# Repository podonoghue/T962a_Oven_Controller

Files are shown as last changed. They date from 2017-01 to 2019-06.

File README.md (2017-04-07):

# T962a Oven Controller Upgrade

This is a replacement controller for a T962a Oven.  
It consists of a complete replacement for the existing controller in a mechnically compatible form.    
It provides open source firmware that provides extended features.  
It also provides a basic JAVA application to control the oven in a more convenient fashion (Work in Progress)

**Features**  
- Supports the two internal thermocouples  
- Support up to two external thermocouples (with expansion board)  
- Supports up to 10 profiles stored in non-volatile memory  
- The current configuration is also stored in non-volatile memory  
- Uses an additional SSR to completely separate the low-voltage and high-voltage components  

**Requirements**  
- It uses a Kinetis microcontroller so requires a compatible programmer e.g. USBDM  
- Firmware development requires Eclipse/KDS and USBDM plugin  

# Software and Firmware

This is a Eclipse workspace.   
 
Basic application - work in progress.  
Firmware for oven controller.  

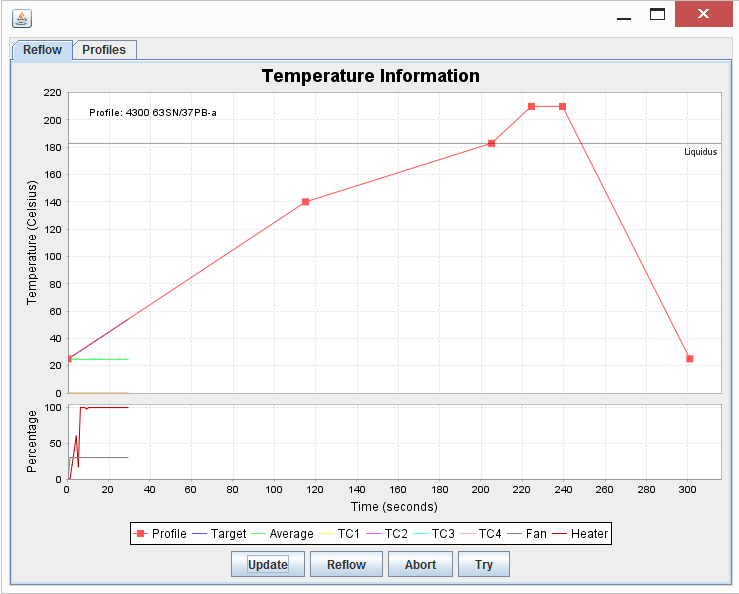
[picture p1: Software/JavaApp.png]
An image Java Application
  

[Available here](https://github.com/podonoghue/T962a_Oven_Controller/tree/master/Software)  

# Windows Drivers (none needed for Linux)

[Available here](https://github.com/podonoghue/T962a_Oven_Controller/tree/master/WinDrivers)  

# Hardware (PCB Designs)

PCB designs for replacement oven controller.  
These are Altium designer projects.  
Gerber files are also provided.  
Bare boards may be ordered from OSH Park

[Hardware designs are available here](https://github.com/podonoghue/T962a_Oven_Controller/tree/master/Hardware)

Main board
====

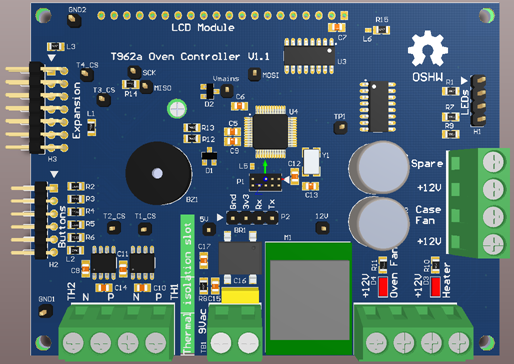
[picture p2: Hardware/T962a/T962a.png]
  

Expansion board
====

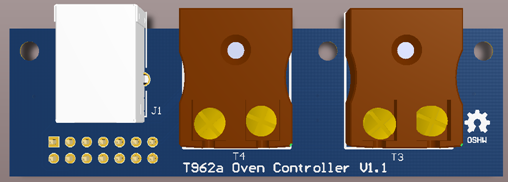
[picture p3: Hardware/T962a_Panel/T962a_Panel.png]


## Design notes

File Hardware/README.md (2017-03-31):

# T962a Hardware (PCB Designs)
  
PCB designs for T962a replacement oven controller.  
These are Altium designer projects.  

Main board
====
Refer to the PDFs in the Project Outputs directory of each project  <a href="T962a/Project%20Outputs%20for%20T962a/T962a.PDF">Main Board</img></a>  

An image Top Board Image  

PCBs may be ordered from OSH park    
Expansion board
====
Refer to the PDFs in the Project Outputs directory of each project  <a href="T962a_Panel/Project%20Outputs%20for%20T962a_Panel/T962a_Panel.PDF">Expansion Board</img></a>  

An image Top Board Image  

PCBs may be ordered from OSH park

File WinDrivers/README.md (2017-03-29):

# T962a Serial Driver  

Files to build Windows CDC driver for T962a controller  
This allows the controller to be accessed as a USB serial port

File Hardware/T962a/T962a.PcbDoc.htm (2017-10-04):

Reporting Options

# File in Previous Format

Date | : | 10/09/2017
Time | : | 8:55:08 PM
Filename | : | C:\Users\podonoghue\Documents\Development\T962a_Oven_Controller\Hardware\T962a\T962a.PcbDoc

Version | Warning

This file was generated by an earlier version of the software

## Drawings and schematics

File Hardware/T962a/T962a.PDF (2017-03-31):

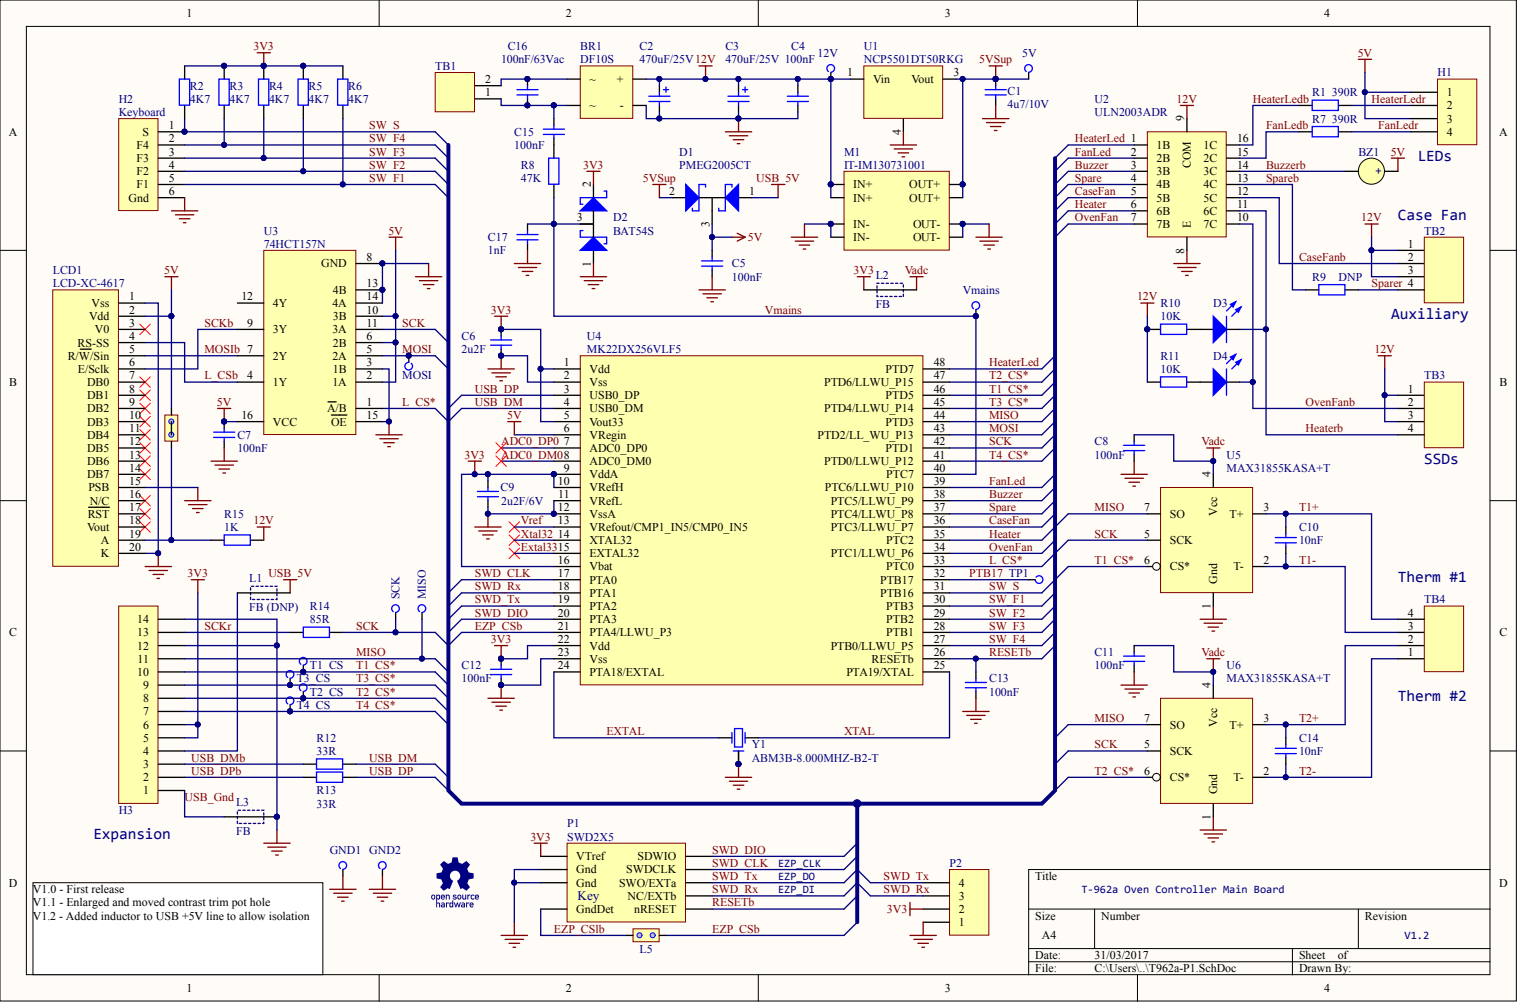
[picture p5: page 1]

SW_F3
SW_F2

CaseFanb

T3_CS T3_CS*
T2_CS T2_CS* | EXTAL | XTAL

USB_DPb | USB_DP

V1.0 - First release
V1.1 - Enlarged and moved contrast trim pot hole
V1.2 - Added inductor to USB +5V line to allow isolation

T-962a Oven Controller Main Board

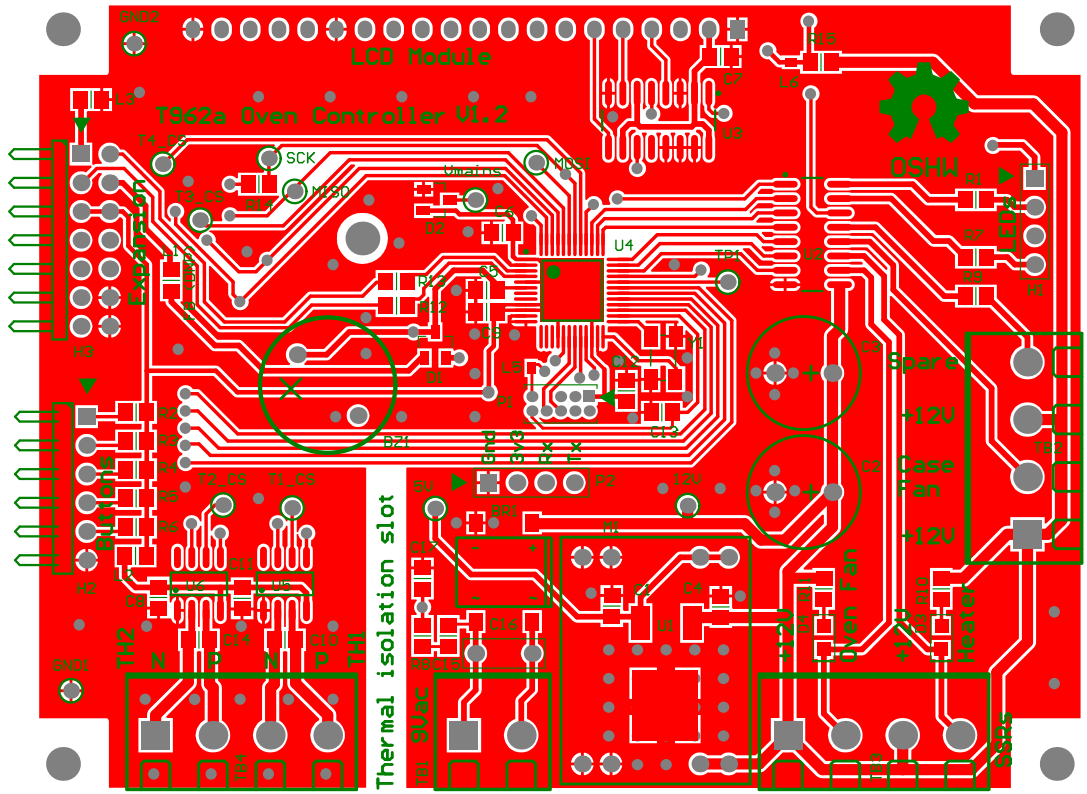
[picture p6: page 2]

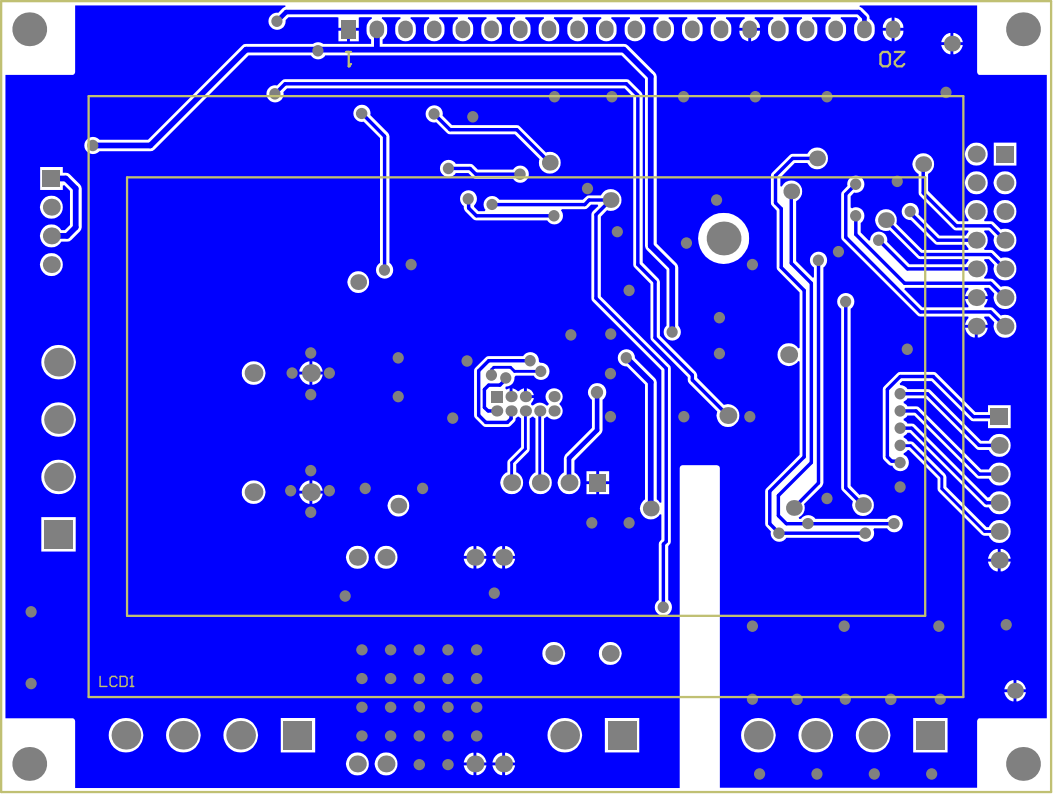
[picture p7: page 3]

Bill of Materials | Bill of Materials For Project [T962a.PrjPCB] (No PCB Document Selected)
Source Data From: | T962a.PrjPCB
Project: | T962a.PrjPCB
Variant: | None
Creation Date: | 31/03/2017 | 11:26:18 AM
Print Date: | 31-Mar-17 | 11:26:27 AM
Footprint | Comment | Farnell PN | Digikey | Designator | Description | Quantity
PCBPIN - 0.9mm | TP | | | 5V, 12V, GND1, GND2, MISO, MOSI, SCK, T1_CS, T2_CS, T3_CS, T4_CS, TP1, Vmains | Test Point | 13
Bridge-SMT | DF10S | 2101164 | | BR1 | bRIDGE rECTIFIER | 1
BUZZER_Small | Buzzer_PCB | | | BZ1 | Buzzer (Adafruit 1536) | 1
CCNP2012-0805 | 4u7/10V | | | C1 | Capacitor SMT 0805 | 1
RB5/10x13mm | 470uF/25V | 2469425 | | C2, C3 | Polarized Capacitor | 2
CCNP2012-0805 | 100nF | | | C4, C5, C7, C8, C11, C12, C13, C15 | Capacitor, Capacitor, Capacitor, Capacitor SMT 0805, Capacitor SMT 0805, Capacitor, Capacitor SMT 0805, Capacitor | 8
CCNP2012-0805 | 2u2F | | | C6 | Capacitor | 1
CCNP2012-0805 | 2u2F/6V | | | C9 | Capacitor | 1
CCNP2012-0805 | 10nF | | | C10, C14 | Capacitor SMT 0805 | 2
CAP - small MKT | 100nF/63Vac | 2429336 | | C16 | Capacitor | 1
CCNP2012-0805 | 1nF | | | C17 | Capacitor | 1
SOT23 | PMEG2005CT | 2459194 | | D1 | Dual Schottky Diode (SMT) | 1
SOT23 | BAT54S | F1467519 | | D2 | Dual Diode (SMT) | 1
LED-SMT-2 | LED Red | 5790839 | | D3, D4 | LED (Red SMT) | 2
HDR1X4S | Header 1x4 | | | H1, P2 | Header, 5-Pin, Right Angle | 2
HDR1X6H | Keyboard | | | H2 | Header, 6-Pin | 1
HDR2X7H | 2x5 Header | | | H3 | Header 2x7 | 1
CR2012-0805 | FB | 1515661 | | L2, L3 | Ferrite Bead (0805) 0.045OHM, 2A | 2
LCD_XC-4617 | LCD-XC-4617 | | | LCD1 | LCD 128 x 64 pixel, ST7920 controller & contrast pot (Jaycar XC-4617) | 1
IT-IM130731001 | IT-IM130731001 | | | M1 | Itead Buck converter | 1
SWD-2x5 | SWD2X5 | | | P1 | SWD Connector 2x5-Pin | 1
CR2012-0805 | 390R | | | R1, R7 | Resistor | 2 5 1 1 2 2 1 1 1 3 1 1 1 1 2 1
CR2012-0805 | 4K7 | | | R2, R3, R4, R5, R6 | Resistor
CR2012-0805 | 47K | | | R8 | Resistor
CR2012-0805 | DNP | | | R9 | Resistor
CR2012-0805 | 10K | | | R10, R11 | Resistor
CR2012-0805 | 33R | | | R12, R13 | Resistor
CR2012-0805 | 85R | | | R14 | Resistor
CR2012-0805 | 1K | | | R15 | Resistor
MOLEX-39544-3002 | Terminal2 | 2396251 | | TB1 | MULTICOMP MC24366 Wire-To-Board Terminal Block
MOLEX-39544-3004 | Terminal4 | 1624302 | | TB2, TB3, TB4 | MULTICOMP MC24368 Wire-To-Board Terminal Block
TO-252 | NCP5501DT50RKG | 2532866 | | U1 | Fixed LDO Voltage Regulator, 2.5V-16V in, 230mV Dropout, 5V/500mA out, TO-252-3
SO-16_N | ULN2003ADR | 1470513 | | U2
SO-16_N | 74HCT157N | | | U3 | Quad 2-1 Multiplexor
TSQFP50P900X900-48M | MK22DX256VLF5 | | | U4 | Arm Cortex M4
SO-8_L | MAX31855KASA+T | 2515622 | | U5, U6
Crystal_SMT - ABM3B | ABM3B-8.000MHZ-B2-T | 2467818 | | Y1 | Crystal 8MHz (MINIATURE SMT ABM3B)
| | | | | | 71
Approved | | Notes

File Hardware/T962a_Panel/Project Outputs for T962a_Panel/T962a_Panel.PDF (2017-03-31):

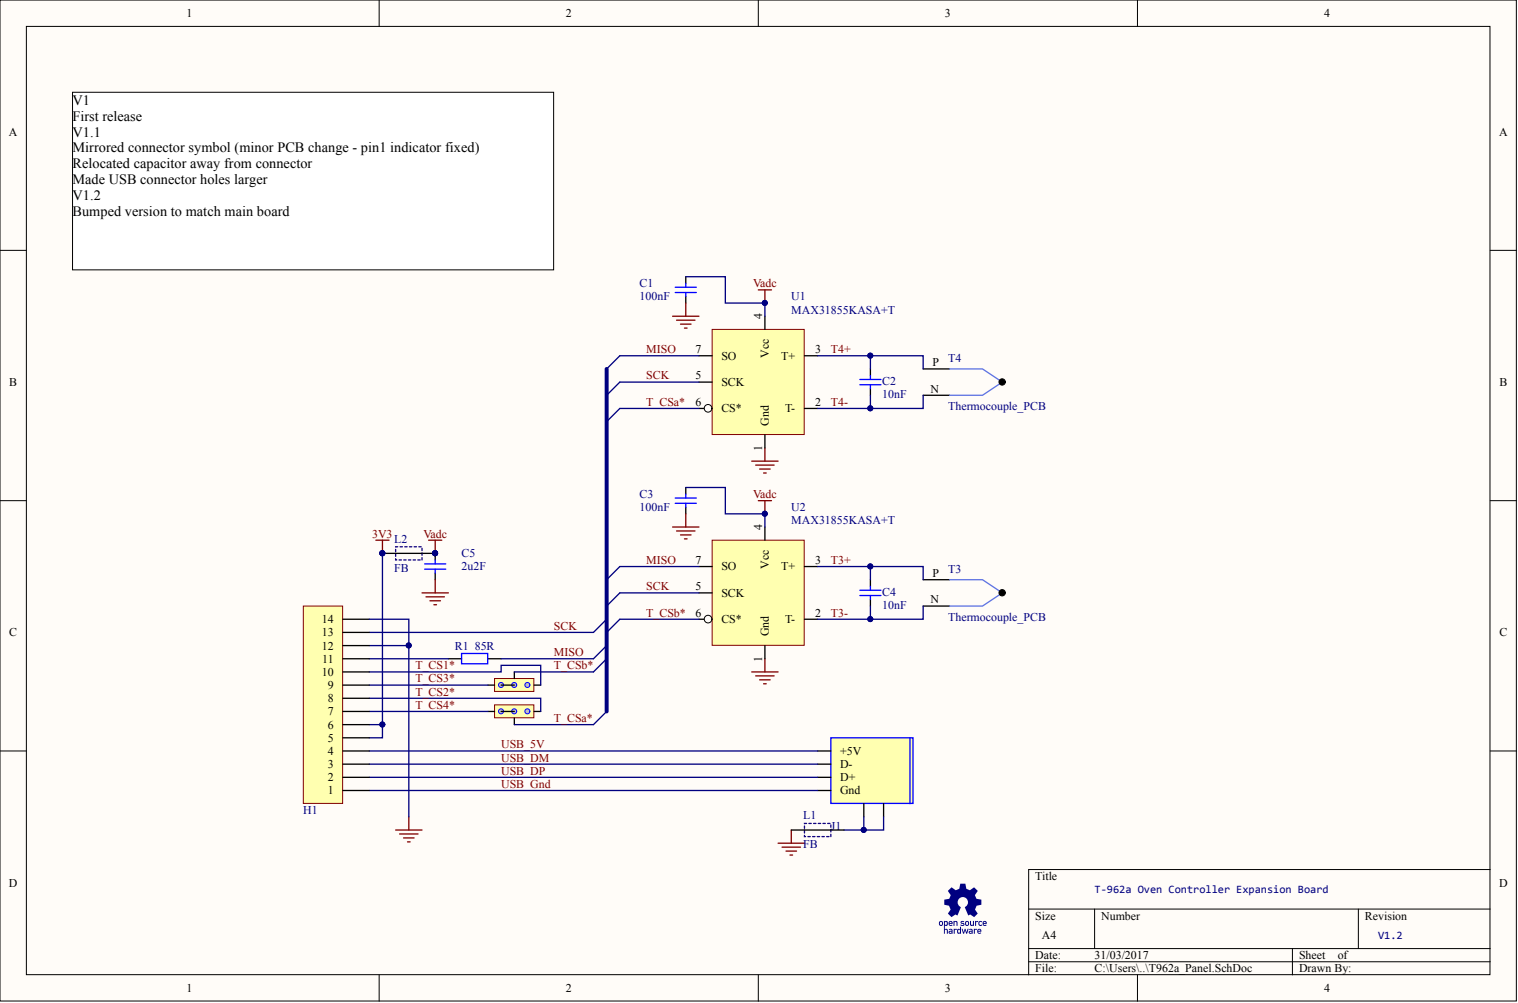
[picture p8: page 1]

First release
Mirrored connector symbol (minor PCB change - pin1 indicator fixed)
Relocated capacitor away from connector
Made USB connector holes larger
Bumped version to match main board

USB_DM
USB_DP
USB_Gnd

T-962a Oven Controller Expansion Board

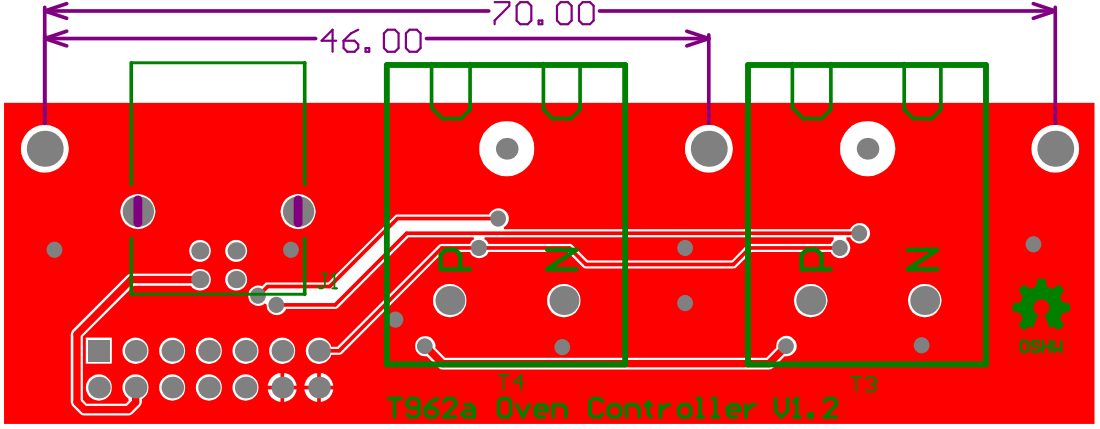
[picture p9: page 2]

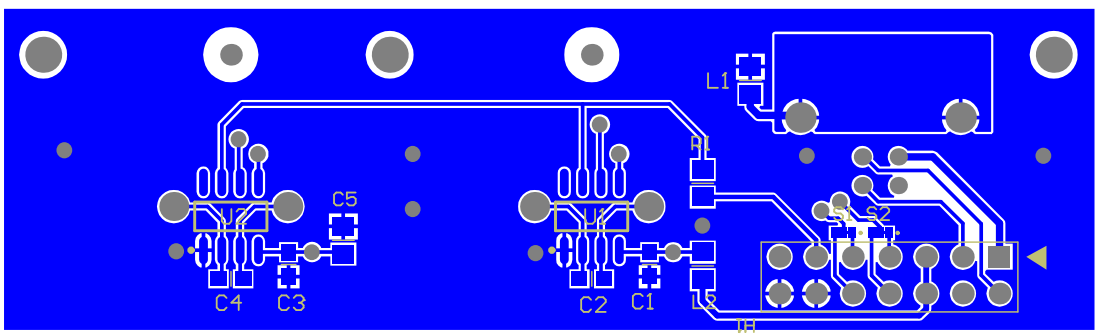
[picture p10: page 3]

Bill of Materials | Bill of Materials For Project [T962a_Panel.PrjPCB] (No PCB Document Selected)
Source Data From: | T962a_Panel.PrjPCB
Project: | T962a_Panel.PrjPCB
Variant: | None
Creation Date: | 31/03/2017 | 11:37:54 AM
Print Date: | 31-Mar-17 | 11:37:59 AM
Footprint | Comment | Farnell PN | Digikey | Designator | Description | Quantity
CCNP1608-0603 | 100nF | | | C1, C3 | Capacitor | 2
CCNP1608-0603 | 10nF | | | C2, C4 | Capacitor | 2
CCNP2012-0805 | 2u2F | | | C5 | Capacitor | 1
HDR2X7S | 2x5 Header | | | H1 | Header 2x7 | 1
USB_BCon - straight pins | USB Type B | | | J1 | USB B Connector | 1
CR2012-0805 | FB | 1515661 | | L1, L2 | Ferrite Bead (0805) 0.045OHM, 2A | 2
CR2012-0805 | 85R | | | R1 | Resistor | 1
ThermoCoupleSocket - PCB mount | Thermocouple_PCB | 2347189 | | T3, T4 | | 2
SO-8_L | MAX31855KASA+T | 2515622 | | U1, U2 | | 2
| | | | | | 14
Approved | | Notes

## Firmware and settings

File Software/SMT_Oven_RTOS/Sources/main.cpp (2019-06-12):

/*
 ============================================================================
 * @file    main.cpp (180.ARM_Peripherals)
 * @brief   Basic C++ demo using GPIO class
 *
 *  Created on: 10/1/2016
 *      Author: podonoghue
 ============================================================================
 */
#include <string.h>
#include <math.h>
#include "cmsis.h"
#include "usb_cdc_interface.h"
#include "system.h"
#include "derivative.h"
#include "hardware.h"
#include "delay.h"
#include "spi.h"
#include "fonts.h"
#include "configure.h"
#include "pid.h"
#include "settings.h"
#include "messageBox.h"
#include "mainMenu.h"
#include "usb.h"
#include "utilities.h"
#include "EditProfile.h"
#include "i2c.h"

class profilesMenu {

public:
   static void run() {
      unsigned profileIndex = ::currentProfileIndex;
      bool needUpdate = true;

      for(;;) {
         if (needUpdate) {
            RunProfile::drawProfile(profiles[profileIndex]);
            lcd.refreshImage();
            lcd.setGraphicMode();
            needUpdate = false;
         }
         switch(buttons.getButton()) {
         case SwitchValue::SW_F1:
            if (profileIndex>0) {
               profileIndex--;
               needUpdate = true;
            }
            break;
         case SwitchValue::SW_F2:
            if ((profileIndex+1)<(sizeof(profiles)/sizeof(profiles[0]))) {
               profileIndex++;
               needUpdate = true;
            }
            break;
         case SwitchValue::SW_F3:
            EditProfile::run(profiles[profileIndex]);
            needUpdate = true;
            break;
         case SwitchValue::SW_S:
            ::currentProfileIndex.operator =(profileIndex);
            return;
         default:
            break;
         }
         __WFI();
      };
   }
};

using namespace USBDM;

void initialise() {
   using namespace USBDM;

   Buzzer::init();
   OvenFanLed::init();
   HeaterLed::init();
   Spare::Ftm::enable();
   Spare::setDutyCycle(0U);
   ovenControl.initialise();
   Tp1::setOutput(PinDriveStrength_High);
   lcd.setFloatFormat(1,Padding_LeadingSpaces,3);
}

int main() {

   console.writeln("Starting Oven");

   console.write("Main thread priority = ").writeln(CMSIS::Thread::getMyPriority());
   CMSIS::Thread::setMyPriority(osPriorityHigh);
   console.write("Main thread lowered priority = ").writeln(CMSIS::Thread::getMyPriority());

   initialise();

   Usb0::initialise();

   mapAllPins();

   if (getError() != E_NO_ERROR) {
      char buff[100];
      lcd.clear();
      lcd.write("Error in initialisation \n  ").writeln(getErrorMessage());
      console.write(buff);
   }

   MainMenu::run();

   // Should not reach here
   for (;;) {
      __BKPT();
   }
   return 0;
}

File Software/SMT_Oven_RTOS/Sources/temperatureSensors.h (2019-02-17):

/**
 * @file TemperatureSensors.h
 *
 *  Created on: 12Mar.,2017
 *      Author: podonoghue
 */

#ifndef SOURCES_TEMPERATURESENSORS_H_
#define SOURCES_TEMPERATURESENSORS_H_

#include <dataPoint.h>
#include <Max31855.h>
#include "cmsis.h"

class TemperatureSensors {

public:
   static constexpr unsigned NUM_THERMOCOUPLES = 4;

private:
   using ThermocoupleStatus = Max31855::ThermocoupleStatus;

   /** Temperature sensors */
   Max31855 fTemperatureSensors[NUM_THERMOCOUPLES] = {
      Max31855(spi, t1_cs, t1Offset, t1Enable),
      Max31855(spi, t2_cs, t2Offset, t2Enable),
      Max31855(spi, t3_cs, t3Offset, t3Enable),
      Max31855(spi, t4_cs, t4Offset, t4Enable),
   };

   /** The thermocouples are averaged this many times on reading. */
   static constexpr int OVERSAMPLES = 4;

   /** Last measurement */
   DataPoint fCurrentMeasurements;

   /** Cold junction references from last measurement */
   float fColdReferences[4];

   /** Mutex used to protect accesses */
   CMSIS::Mutex fMutex;

   /** Average of temperatures */
   float fAverageTemperature = 0;

public:
   /**
    * Constructor
    */
   TemperatureSensors() {
   }

   /**
    * Destructor
    */
   virtual ~TemperatureSensors() {
   }

   /**
    * Update current readings from thermocouples
    */
   void updateMeasurements() {
      // Lock while changes made
//      PulseTp tp(3);
      fMutex.wait();
      {
//      PulseTp tp(6);
      float temperatures[NUM_THERMOCOUPLES];
      ThermocoupleStatus status[NUM_THERMOCOUPLES];
      int   foundSensorCount   = 0;
      float averageTemperature = 0;
      for (unsigned t=0; t<NUM_THERMOCOUPLES; t++) {
         // Average each thermocouple
         temperatures[t]    = 0;
         fColdReferences[t] = 0;
         for (int overSample=0; overSample<OVERSAMPLES; overSample++) {
            float temperature;
            float coldReference;
            status[t] = fTemperatureSensors[t].getNewReading(temperature, coldReference);
            temperatures[t]    += temperature;
            fColdReferences[t] += coldReference;
            if (status[t] == Max31855::TH_ENABLED) {
               foundSensorCount++;
               averageTemperature +=temperature;
            }
         }
         // Scale for average
         temperatures[t]     /= OVERSAMPLES;
         fColdReferences[t]  /= OVERSAMPLES;
      }
      if (foundSensorCount==0) {
         // Safe value to return!
         averageTemperature = NAN;
      }
      else {
         averageTemperature /= foundSensorCount;
      }
      fAverageTemperature = averageTemperature;
      fCurrentMeasurements.setState(s_off);
      fCurrentMeasurements.setTargetTemperature(0);
      fCurrentMeasurements.setFan(0);
      fCurrentMeasurements.setHeater(0);
      fCurrentMeasurements.setThermocouplePoint(temperatures, status);
      }
      fMutex.release();
   }
   /**
    * Get last measured temperature\n
    * This is an average of the active thermocouples
    *
    * @return Averaged oven temperature
    */
   float getLastTemperature() {
      return fAverageTemperature;
   }
   /**
    * Get last measured thermocouple values
    *
    * @return Reference to set of measurements (DataPoint)
    * @return This will be incomplete as only the thermocouple information is present e.g.
    *         state etc is not valid.
    */
   const DataPoint &getLastMeasurement() {
      return fCurrentMeasurements;
   }
   /**
    * Return the cold reference temperature from the last call
    * to measureNewDataPoint for given thermocouple
    *
    * @param[in] index Index of thermocouple
    *
    * @return Cold reference temperature
    */
   float getColdReferences(int index) {
      return fColdReferences[index];
   }
   /**
    * Get the thermocouple sensor
    *
    * @param[in]  index Index of sensor to retrieve
    *
    * @return Reference to sensor
    */
   Max31855 &getThermocouple(int index) {
      return fTemperatureSensors[index];
   }
   /**
    * Get case temperature \n
    * This is actually the cold reference temperature for one of the internal Max31855s
    */
   float getCaseTemperature() {
      float temperature, coldReference;
      ThermocoupleStatus status = fTemperatureSensors[0].getLastReading(temperature, coldReference);
      if (status == Max31855::TH_MISSING) {
         // No MAX31855!
         return 50.0;
      }
      return coldReference;
   }
};

#endif /* SOURCES_TEMPERATURESENSORS_H_ */

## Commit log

2016-09-28 V1.0.0 Initial commit of hardware (PCB design)
    [T962a-P1.SchDoc, T962a-P2.SchDoc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]
2016-09-28 V1.0.0 Comments, reset to default value (+/- together)
    [settings.cpp]
2016-09-29 V1.0.0 Added documentation, added LED handling
2016-09-29 V1.0.0 Extended Motor dialogue
2016-09-30 V1.0.0 Corrected pin mapping
2016-09-30 V1.0.0 Corrected HeaterLed mapping
2016-09-30 V1.0.0 Added heaterSetting safety checks
2016-09-30 V1.0.0 Moved Buzzer to lower height near bottom, Uprated capacitor
    [T962a-P1.SchDoc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]
2016-10-02 V1.0.0 Added case fan controller
2016-10-02 V1.0.0 Changed profile format (Added fan control etc)
2016-10-04 V1.0.0 Changed Expansion connector (added Gnds), Added series termination
    [T962a-P1.SchDoc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]
2016-10-11 V1.0.0 Regenerated PCB outputs for production
    [T962a-P1.SchDoc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]
2016-10-11 V1.0.0 Minor (DRC and .gitignore html and drc)
    [T962a.PrjPCB, T962a_Panel.PrjPCB]
2016-10-16 V1.0.0 Added CDC driver build
2016-10-19 V1.0.0 Renamed directory
    [T962a-P1.SchDoc, T962a-P2.SchDoc, T962a.PcbDoc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]
2016-11-04 V1.1.0 Review of boards after production - Minor fixes
    [T962a-P1.SchDoc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]
2016-11-04 V1.1.0 Added serenum to driver (and simplified)
2016-11-06 V1.1.0 Rename driver
2016-11-13 V1.1.0 Cosmetic
    [T962a_Panel.GTP]
2016-11-29 V1.1.0 Fixed profile getting 'stuck' due to tolerance in PID control
2016-11-29 V1.1.0 Changed print message
2016-11-29 V1.1.0 Reduced MAX31855 communication speed (bug fixing daughter board)
2017-03-01 V1.1.0 Updated driver
2017-03-12 V1.1.0 Corrected processor (no PCB changes)
    [T962a-P1.SchDoc, T962a.PcbDoc]
2017-03-14 V1.1.0 Changed SwitchValue to class to better encapsulate meaning
2017-03-14 V1.1.0 Added TemperatureSensors to encapsulate thermocouple handling
2017-03-26 V1.1.0 Removed non-RTOS version as not workable
    [configure.cpp]
2017-03-26 V1.1.0 Reduced interrupt latency (needed for USB)
2017-03-27 V1.1.0 Added mutex to SPI
2017-03-31 V1.2 Hardware - Added Isolation inductor (FB DNP) for 5V from USB
    [T962a-P1.SchDoc, T962a.PcbDoc, T962a.PrjPCB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]
2017-03-31 V2.0 Software - Added PID parameters to settings
2017-03-31 V2.0 Software - Added CMSIS mutex to I2C
2017-04-05 V2.0 Firmware - Added remote handling of PID parameters
2017-04-07 V2.0 Software - Split Temperature and Percentage graphs
2017-04-07 V2.0 Firmware - Changed profile format (added liquidus, pre-heat format)
2017-04-09 V2.0 Firmware - Ensure FlexRAM is initialised in correct order on initial boot
    [settings.cpp]
2017-04-16 V2.0 Firmware - Update non-volatile code to current version
2017-04-17 V2.0 Firmware - Update flash code to current version. Cleaned up .gitignore files
2017-06-03 V2.1 Firmware - Changed startup and initialisation with new CMSIS threaded start
    [RTX_Conf_CM.cfg]
2017-06-04 V2.1 Firmware - Added terminate code (reduce code size by removing unnecessary de-mangling code)
2017-06-04 V2.1 Firmware - Documentation fixes
    [dataPoint.h]
2018-02-18 V2.2 Firmware - Updated USBDM stationery
    [RTX_Conf_CM.cfg]
2019-01-27 V2.5 Firmware - Updated USBDM stationery (Mostly USB)
    [RTX_Conf_CM.cfg]
2019-02-07 V2.5 Firmware - General review
    [RTX_Conf_CM.cfg]
2019-02-17 V2.5 Firmware - USB update etc.
    [RTX_Conf_CM.cfg]
2019-02-26 V2.5 Firmware - Updated to use formatted_io rather than printf family
2019-02-27 V2.5 Firmware - Abort command is now more persistent with releasing mutex (in case of overlapped commands)
